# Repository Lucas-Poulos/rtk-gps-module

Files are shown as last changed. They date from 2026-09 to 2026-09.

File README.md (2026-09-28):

# rtk-gps-module

A cheap, solder-down **RTK GNSS module** that gets you centimetre-level
position. Dual-band L1 + L5, castellated edges, and a USB-C port so it also
works on its own with nothing but a cable.

**Status: schematic complete and verified. PCB layout is the next phase.**

```
    ┌──── u.FL ────┐
    │ active       │   50 Ω CPWG, 0.38 mm
    │ dual-band    ├──► ESD ─► bias tee ─► DC block ─► π ─► SAW ─┐
    │ antenna      │    0.25pF   68 nH      100 pF    0R   L1+L5 │
    └──────────────┘        ▲                                    ▼
                            │                            ┌───────────────┐
                    ANT_ON ─┴─ PMOS switch               │   LC29H (DA)  │
                                                         │  dual-band    │
    USB-C ─► ESD ─► BAT54C OR ─► AP2112K 3V3 ────────────┤  RTK rover    │
      │                ▲                                 │               │
      │             5V_IN (carrier)                      │  UART1  1PPS  │
      └─► CH340N ──────────────────────────── UART ──────┤               │
                                        1k/10k divider   └───────┬───────┘
                                                                 │
                              24 castellated pads, 1.27 mm ──────┘
```

## What it does

Feed it **RTCM3 corrections** over the UART — from an NTRIP client on a
phone, a Raspberry Pi or a PC — and it resolves carrier phase to **1–2 cm
horizontal**, versus the 2–3 m you get from ordinary GPS.

Corrections come from the host, so there is **no radio on the board**:
nothing to license, nothing to certify, and one less thing to pay for.

| | |
|---|---|
| Receiver | Quectel LC29H (DA), dual-band RTK rover |
| Bands | L1 / E1 / B1 / G1 **and** L5 / E5a / B2a |
| Constellations | GPS, GLONASS, Galileo, BeiDou, QZSS, SBAS |
| RTK accuracy | ~1–2 cm CEP, open sky, within 1 km of the base |
| Update rate | up to 10 Hz |
| Corrections in | RTCM3 over UART1 |
| Timing out | 1PPS, rising-edge synchronised |
| Supply | 5 V from USB-C **or** 5 V from the carrier board |
| Logic | 3.3 V (plus a 1.8 V debug domain, see below) |
| Interface | USB-C (CH340N) and 24 castellated pads on 1.27 mm |
| **Parts cost** | **$27.10** per board at qty 1 |

The receiver is **88 % of the bill**. Everything else together is $1.56.
Nothing but the receiver is worth cost-optimising.

## Everything else is discrete

There is no way to make an RTK receiver from discrete components — carrier
phase needs a correlator ASIC. So the receiver and its SAW filter are ICs
and *everything around them* is built from single transistors and passives
rather than bought as a block:

- **Antenna bias tee** — a 68 nH choke, a 100 pF block, and a PMOS/NPN pair
  switched by `ANT_ON`, with a 10 Ω resistor limiting a shorted antenna to
  ~330 mA.
- **5 V ORing** — one BAT54C, anodes to USB and to the carrier's 5 V,
  cathode to the LDO. USB and carrier power can both be present and neither
  back-feeds the other.
- **Backup domain** — a second BAT54C ORs 3V3 with an optional external
  cell on `VBCKP_EXT`, so the ephemeris cache survives and the module
  hot-starts in ~1 s instead of cold-starting in ~30 s.
- **RX level shift** — a 1 k / 10 k divider, because `RXD1` is specified
  VIHmax **3.08 V** and a 3.3 V host would exceed it.
- **1PPS indicator** — one MMBT3904, because 1PPS is guaranteed only 2.1 V
  high and would drive an LED dimly while loading the edge.

## The impedance work

Fully derived rather than asserted — see **[docs/impedance.md](docs/impedance.md)**.
Short version:

- The antenna line is a **conductor-backed CPWG**, not microstrip. Solving
  the conformal-mapping model for JLCPCB's 4-layer JLC04161H-3313 stackup
  gives **0.38 mm at 0.2 mm gap → 50.19 Ω**. Treating it as microstrip
  would say 0.41 mm and land it near 47 Ω.
- The SAW's ports are **50 Ω ∥ 5.1 nH**, not 50 Ω, so `L302`/`L303` are
  part of the impedance, not optional.
- The ESD diode is **0.25 pF**. An ordinary ESD part at 10–50 pF would
  shunt the antenna signal away.
- The number lives in `tools/calc_impedance.py`, and `make check` fails
  if the project's RF netclass drifts away from it.

## Pinout

24 castellated pads on 1.27 mm — drops onto 0.1 in perfboard.

**Left edge (J501)**

| Pad | Name | Notes |
|---:|---|---|
| 1 | GND | |
| 2 | 5V_IN | ORed with USB VBUS |
| 3 | 3V3 | LDO output |
| 4 | VBCKP_EXT | optional backup cell / supercap |
| 5 | GND | |
| 6 | TXD1 | receiver → host, NMEA / PQTM |
| 7 | RXD1 | host → receiver, RTCM3 in |
| 8 | 1PPS | rising edge |
| 9 | RESET_N | active low, pulled up on-board |
| 10 | WAKEUP | needs ≥ 3.0 V to wake |
| 11 | VDD_EXT | 2.8 V out, **100 mA max** |
| 12 | GND | |

**Right edge (J502)**

| Pad | Name | Notes |
|---:|---|---|
| 1 | GND | |
| 2 | ANT_ON | antenna switch control |
| 3 | I2C_SDA | via DNP link |
| 4 | I2C_SCL | via DNP link |
| 5 | TXD2 | **1.8 V domain**, via DNP link |
| 6 | RXD2 | **1.8 V domain**, via DNP link |
| 7 | D_SEL1 | **1.8 V domain**, via DNP link |
| 8 | D_SEL2 | **1.8 V domain**, via DNP link |
| 9 | GND | |
| 10–11 | — | spare |
| 12 | GND | |

> **Pads 5–8 on the right edge are not 3.3 V tolerant.** VIHmax is 2.1 V.
> Each reaches the edge only through an unfitted link, so a default board
> cannot present them to a 3.3 V host by accident.

`D_SEL1 = D_SEL2 = 0` selects UART1 and is the on-chip default via 75 kΩ
pulldowns, so the fitted board needs no strapping parts at all.

## Repository layout

```
design/        THE PROJECT. Open it in KiCad, edit it, save it.
  lib/         the two symbols and three footprints stock KiCad lacks
tools/         helpers that READ design/ -- none of them write to it
  check.py             ERC + netlist + sourcing + impedance
  gen_bom.py           BOM, read from the schematic
  calc_impedance.py    the 50 Ω derivation
  fetch_datasheets.py  pulls the vendor PDFs (not committed)
  bootstrap/           the generators that built v1 -- NOT authoritative
Makefile       run `make` to list every target
.githooks/     optional pre-commit hook, ERC errors only
manufacturing/ BOM.md, BOM-dnp.md, bom_jlcpcb.csv
docs/          editing.md, impedance.md, schematic.pdf
datasheets/    README + fetch script; the PDFs are not ours to redistribute
analysis/      ERC report and netlist (gitignored, regenerated on demand)
```

**`design/` is a normal KiCad project.** Edit it directly. Nothing
regenerates it, and nothing in `tools/` writes to it.

## Working on it

```bash
make open       # open in KiCad -- edit and save freely
make check      # ERC + netlist + sourcing + impedance, all read-only
make bom        # rebuild manufacturing/ after a parts change
make            # list every target
```

Read **[docs/editing.md](docs/editing.md)** before changing the RF path
or anything on the LC29H — there are four traps on this board that KiCad
will not warn you about (a 3.08 V limit on `RXD1`, a 1.8 V pin domain,
two supply pins that are outputs, and three pins that must float).

`make check` reads `design/` and never writes to it. It exports a fresh
netlist and a fresh ERC report and asserts against those:

- **ERC** — must be clean *and* the report must be newly written. A stale
  report from an earlier run reads exactly like a pass, and `kicad-cli`
  writes no report at all when the schematic fails to parse. Verified by
  injecting a deliberate fault and confirming ERC caught it on the right
  sub-sheet.
- **Netclass** — the exported per-net class is read back, because KiCad
  accepts a netclass pattern that matches nothing without complaining and
  a 50 Ω line silently falls back to the default track width. *(This
  caught a real bug: `/regex/` patterns are accepted by the file format
  and match nothing — KiCad uses wildcards, and local nets carry their
  sheet path.)*
- **Critical nets** — the RF chain, the bias tee and the RXD1 divider are
  asserted pin by pin, so none of them gets rerouted by accident. Rewire
  one on purpose and it tells you exactly what changed.
- **LC29H pin rules** — grounds grounded, the three RESERVED pins still
  floating, `VDD_EXT` never tied to 3V3.
- **Sourcing** — every fitted part must carry a resolved `Cxxxxx`.
- **Impedance** — the RF netclass width must still match what
  `tools/calc_impedance.py` derives, and still land within 5 % of 50 Ω.

## Building one

The BOM is in [manufacturing/BOM.md](manufacturing/BOM.md), with
`bom_jlcpcb.csv` ready for JLCPCB assembly and
[BOM-dnp.md](manufacturing/BOM-dnp.md) listing the unfitted options.

Prices and stock were read from LCSC on 2026-09-28 and frozen for
traceability — **re-check before ordering.** LC29H stock in particular was
thin (22 pcs). `LC29HBS` (`C21385845`) is the RTK *base station* variant and
`LC29HAA` (`C22403415`) has no RTK engine; both share the footprint, so
check you are buying the one you mean.

You also need an **active dual-band L1+L5 antenna** with NF < 1.5 dB, gain
< 17 dB, and its SAW ahead of its LNA.

## Caveats

- **Not built yet.** The schematic is verified; no board has been
  fabricated, so nothing here is confirmed against hardware.
- **The LC29H (DA) pinout is contested by its own datasheet.** Figure 4
  and Table 6 disagree about pins 15–19. The V1.3 revision history settles
  it in Table 6's favour (the changes applied only to the EA variant), and
  the design follows Table 6 — but those four pins reach the edge only
  through unfitted links, so the board is correct either way.
- Prices are a snapshot, not a quote.

## Licence

Hardware under [CERN-OHL-P v2](LICENSE); the scripts under the same terms.
Permissive — do what you like, no reciprocity required.

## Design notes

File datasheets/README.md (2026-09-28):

# Datasheets

The PDFs this design was transcribed from are **not committed** — they are
Quectel's and Qualcomm's documents, not mine to redistribute. Fetch them:

```bash
python3 tools/fetch_datasheets.py
```

| File | Document | Used for |
|---|---|---|
| `LC29H_Hardware_Design_V1.3.pdf` | Quectel LC29H Series Hardware Design, V1.3 (2024-07-30) | Table 6 pin description, Figure 4 pin assignment, Figure 17 active-antenna reference, Figure 19 land pattern, section 3.2 decoupling |
| `SAW_B39162B8389P810.pdf` | Qualcomm RF360 B8389 SAW RF Filter, V2.1 (2022-11-15) | section 4 pin configuration, section 5 matching circuit (50 Ω ∥ 5.1 nH), section 6 pass bands, Figure 2 land pattern |

Everything transcribed from them is cited in place — see
`tools/bootstrap/gen_custom_symbols.py` and `tools/bootstrap/gen_footprints.py`.

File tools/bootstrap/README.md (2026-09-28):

# Bootstrap generators — not authoritative

**Do not run these.** They produced the first version of `design/`, and
that is all they are for now. `design/` is the source of truth: it is
hand-edited in KiCad, and re-running `gen_project.py` would overwrite
your work with the design as it stood on 2026-09-28.

They are kept because two of them contain work that is hard to redo and
worth reading:

| File | What is worth keeping |
|---|---|
| `gen_custom_symbols.py` | The LC29H pinout, transcribed pin by pin from the hardware design guide's Table 6, with the electrical type of each pin justified in comments. Its `verify()` holds a **second, independent transcription** of the same table — they were written to disagree loudly if either was typed wrong. Also the reasoning that settles the (DA) variant's contradictory pinout. |
| `gen_footprints.py` | The LC29H land pattern derived from Figure 19, including why the 24 pads are in two uneven groups, and the B8389 land pattern from its Figure 2. |
| `gen_project.py` | The parts catalogue: every LCSC number resolved against the live catalogue on 2026-09-28, with the JLCPCB basic/extended split. |
| `wire_sheets.py` | The connectivity, plus a docstring listing the pin traps — duplicated `I/O1` pins on the USBLC6, BAT54C's common cathode on pin 3, KiCad's cathode-is-pin-1 convention. |
| `verify_project.py` | The old 146-check gate. Superseded by `tools/check.py`, which checks the same design without regenerating it. |

If you need any of that, read it. The live equivalents are:

- `tools/check.py` — the checks, read-only
- `tools/gen_bom.py` — the BOM, read from the schematic
- `tools/calc_impedance.py` — the 50 Ω derivation, still used and still
  checked against the project's RF netclass

## If you ever do want to run one

You would be replacing `design/` wholesale. Take a branch first:

```bash
git switch -c regenerate
python3 tools/bootstrap/gen_project.py
git diff --stat design/       # this will be enormous
```

Expect a large diff even with no design change, because KiCad has since
rewritten every file in its own canonical format.

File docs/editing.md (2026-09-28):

# Editing this project

It is a normal KiCad 10 project. Open it, change it, save it.

```bash
make open        # or just double-click design/rtk-gps-module.kicad_pro
```

There is no generator to fight, no regeneration step, and nothing that
overwrites your edits. `design/` is the source of truth.

After you save:

```bash
make check       # ERC + netlist + sourcing + impedance, all read-only
make bom         # rebuild manufacturing/ if you changed parts
make pdf         # re-plot docs/schematic.pdf
```

`make check` never writes to `design/`.

---

## Adding or changing a part

Do it in KiCad. The one thing to remember: **set the `LCSC` field**, or
the part silently vanishes from the BOM at order time. `make check`
catches it:

```
R103 (2.2k) has no resolved LCSC number. Set its LCSC field in KiCad,
or mark it DNP.
```

Resolve the real number first — never invent one:

```bash
python3 ~/.claude/skills/lcsc/scripts/search_lcsc.py "0402 2.2k" --details
```

Then in KiCad: select the symbol, `E`, and set the fields the BOM reads:

| Field | Example | Used for |
|---|---|---|
| `LCSC` | `C25879` | ordering, JLCPCB CSV |
| `MPN` | `0402WGF2201TCE` | the BOM line |
| `Manufacturer` | `UNI-ROYAL` | the BOM line |
| `DNP` | `yes` | excludes it from the fitted BOM |

For a not-fitted part, also add its reason to `DNP_REASON` in
`tools/gen_bom.py` so `BOM-dnp.md` explains why the footprint exists.

Prices live in `PRICES` in `tools/gen_bom.py` — a frozen snapshot from
2026-09-28, kept for traceability rather than accuracy. Refresh before
ordering.

---

## Four things that will bite you

These are all real, all specific to this board, and none of them are
things KiCad warns about.

### 1. `RXD1` cannot take 3.3 V

The LC29H specifies `RXD1` VIHmax **3.08 V**. `R205`/`R212` (1 k/10 k)
divide a 3.3 V host down to 3.0 V, and the divider sits **at the module
pin** so it protects the castellated pad and the USB bridge with one
pair of resistors. Delete it and you are over spec on a $24 part.

### 2. `D_SEL1`/`D_SEL2`, `TXD2`/`RXD2` are a 1.8 V domain

VIHmax is **2.1 V**. They cannot be strapped to `VDD_EXT` (2.8 V) or
3V3. The default `0,0` selects UART1 via internal 75 kΩ pulldowns, which
is what this board wants, so the fitted build needs no strapping parts.

### 3. `VDD_EXT` (pin 7) and `VDD_RF` (pin 9) are OUTPUTS

Typed `power_out` so ERC rejects driving them. `VDD_EXT` is 2.8 V at
100 mA max — tying it to 3V3 shorts two regulators together.

### 4. Pins 2, 4, 17 must float

Datasheet Table 6: *"must be left N/C and cannot be connected to power
or GND."* Typed `no_connect`; `make check` asserts each still lands on
its own unconnected net.

---

## The RF path

If you touch anything between `J301` and `U201` pin 11, read
[impedance.md](impedance.md) first. Three specifics:

- The antenna line is **50 Ω CPWG at 0.38 mm** with a 0.2 mm gap, derived
  in `tools/calc_impedance.py`. If you change the width in the RF
  netclass, `make check` fails until the model agrees.
- The SAW's ports are **50 Ω ∥ 5.1 nH**. `L302`/`L303` are part of the
  impedance, not optional decoration.
- `D301` is chosen for **0.25 pF**, not its clamp voltage. A normal ESD
  diode at 10–50 pF shunts the antenna signal away.

`make check` pins down the exact wiring of the RF chain, the bias tee and
the RXD1 divider. If you rewire one deliberately, it tells you what
changed and where to update the expectation:

```
net '/RF/ANT_RF' was rewired:
       missing ['L301.2']
       extra   ['L301.1']
       If that was deliberate, update CRITICAL_NETS in tools/check.py
```

---

## Netclasses are wildcards, not regex

If `make check` says a net fell back to `Default`, this is why. KiCad's
netclass patterns use `*` and `?` — a pattern written `/^ANT_RF$/` is
accepted by the file format, displays correctly in the GUI, and **matches
nothing**. Local nets also carry their sheet path (`/RF/ANT_RF`), so a
pattern for one needs a leading `*`.

This already bit the project once: the 50 Ω antenna line was silently on
the default track width. That is the only reason `make check` reads the
exported per-net class back.

---

## The pre-commit hook

`make hooks` installs one. It blocks on **ERC errors only** — never on
warnings, never on formatting, and it skips entirely while KiCad has the
project open. `make unhook` removes it; `git commit --no-verify` bypasses
it once.

---

## What nothing checks

- **The pinout tables in `README.md`** — hand-maintained. If you change
  `J501`/`J502`, change them too.
- **Whether the design works.** No board has been fabricated. ERC proves
  the netlist is self-consistent; it says nothing about whether the
  circuit is correct.

---

## Where the old generators went

`tools/bootstrap/`. They built the first version of `design/` and are no
longer authoritative — see the README there. Worth reading for the
datasheet transcription and the reasoning about the LC29H's
self-contradictory pinout, but do not run them: they would overwrite
your edits with the design as it stood on 2026-09-28.

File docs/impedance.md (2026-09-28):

# Impedance and the RF path

Everything on this board that matters at 1.2–1.6 GHz, and why each number
is what it is. The numbers here are not prose — `tools/calc_impedance.py`
derives them, and `make check` fails if the project's RF netclass drifts
away from what the model says.

```
make impedance
```

## Why the receiver cares

The LC29H hardware design guide types pin 11 (`RF_IN`) as an analog input
with **"50 Ω characteristic impedance"** (Table 6) and asks for the track to
it to be controlled and short. A GNSS signal arrives at roughly −130 dBm.
There is no margin to give away: every dB lost between the antenna and the
correlator is a dB of carrier-to-noise, and RTK needs carrier *phase*, which
degrades faster than pseudorange does as C/N₀ falls.

## The line

The antenna track is a **conductor-backed coplanar waveguide** (CPWG): a
signal trace on L1 with coplanar ground pour either side *and* a solid
ground plane on L2 underneath. That is not the same thing as microstrip,
and the difference is not small — the coplanar gaps add capacitance, so a
CPWG needs a **narrower** trace than a microstrip for the same impedance.

| Model | Width for 50 Ω |
|---|---|
| Plain microstrip (wrong here) | 0.410 mm |
| CPWG, 0.2 mm gap (correct) | 0.382 mm |
| **Built** | **0.38 mm** → 50.19 Ω |

Building the microstrip number on a board that is actually CPWG would land
the line near 47 Ω. That is inside most fab tolerances and would probably
still work — which is exactly why it is worth getting right on purpose
rather than by luck.

### Stackup

JLCPCB four-layer 1.6 mm, **JLC04161H-3313** — their default, and the one
this board is costed against.

```
L1   35 µm copper        <- antenna track here
     0.2104 mm prepreg   <- h
L2   ground plane        <- solid, unbroken under the whole RF path
     1.065 mm core
L3
     0.2104 mm prepreg
L4   35 µm copper
```

`εr = 4.3` for Shengyi S1000-2M around 1.5 GHz. The datasheet quotes 4.4 at
1 MHz and it falls with frequency.

### The model

Conformal mapping, per Simons, *Coplanar Waveguide Circuits, Components and
Systems*, ch. 3:

```
a  = W/2
b  = W/2 + G
k1 = a/b
k2 = tanh(πa/2h) / tanh(πb/2h)
R  = K(k)/K(k')          K = complete elliptic integral, 1st kind

εeff = (1 + εr·R2/R1) / (1 + R2/R1)
Z0   = 60π / √εeff / (R1 + R2)
```

### Tolerance

| Variation | Z₀ |
|---|---|
| εr = 4.1 | 51.25 Ω |
| εr = 4.3 (nominal) | 50.19 Ω |
| εr = 4.5 | 49.19 Ω |
| W − 0.02 mm (etch) | 51.76 Ω |
| W + 0.02 mm (etch) | 48.72 Ω |

Worst case lands inside ±4 %. JLCPCB hold ±10 % on controlled impedance, so
the design is not the limiting factor.

### Length

εeff = 3.107, so the guided wavelength at L1 (1575.42 MHz) is **108 mm**.
Keep the antenna track under λ/20 = **5.4 mm** and its length stops
mattering — no tuning, no stub effects, nothing to model. The u.FL connector
should sit directly beside the SAW, and the SAW directly beside pin 11.

## Layout rules for the PCB stage

Not yet built — the PCB is the next phase — but these follow from the above
and should be treated as constraints, not preferences.

1. **L2 is solid ground under the entire RF path.** A split or a via
   antipad chain under the track changes the return path, and the impedance
   with it. This is the single easiest way to ruin the work above.
2. **Stitch the coplanar pours** either side of the track with vias to L2 at
   ≤ λ/20 ≈ 5 mm — closer near the connector and the SAW. Unstitched
   coplanar pour is a resonator, not a ground.
3. **Keep the chain short and straight**: u.FL → ESD → bias tee tap →
   DC block → π → SAW → RF_IN. Quectel's guide asks for the SAW close to
   pin 11 specifically.
4. **L301 (the bias choke) taps the line, it does not sit in it.** Route the
   proximal pad of L301 onto the RF trace; the DC side goes away from it.
5. **No other signal crosses the RF path on any layer.** The switching
   antenna supply, the USB pair and the UART all stay clear.
6. **The u.FL ground pads want their own via cluster**, not a thin neck to
   the pour.

## The rest of the RF chain

### Bias tee

`L301` = 68 nH wirewound (Murata LQW15AN68NG00D). Quectel specify ≥ 68 nH.
The point of the choke is to be a high impedance across both bands while
passing DC:

| Band | f | \|Z\| of 68 nH |
|---|---|---|
| L5 / E5a / B2a | 1176.45 MHz | 502 Ω |
| L1 / E1 / B1 | 1575.42 MHz | 673 Ω |

Both are ≫ 50 Ω, so the tap costs a small fraction of a dB. A **ferrite
bead must not be substituted here** — a bead is deliberately lossy at these
frequencies, which is the opposite of what a bias tee needs.

`C301` = 100 pF C0G blocks that DC out of the receiver. At 1.5 GHz its
reactance is ~1 Ω, invisible in a 50 Ω line.

### ESD

`D301` = RF1256-000, **0.25 pF** junction capacitance. The LC29H guide caps
this at 0.6 pF. An ordinary ESD diode at 10–50 pF would sit across the
antenna node as a shunt of a few ohms at L1 and simply short the signal
away. This is a case where the "equivalent part" is not equivalent at all.

### The SAW, and its matching

`FL301` = Qualcomm RF360 **B39162B8389P810**, the dual-band part Quectel
names in their own reference design.

| | Band 1 | Band 2 |
|---|---|---|
| Centre | 1176.45 MHz | 1583 MHz |
| Pass | 1166.22–1186.68 | 1559–1607 |
| Insertion loss (typ) | 1.0 dB | 1.8 dB |
| Covers | L5, E5a, B2a | L1, E1, B1, G1 |

Out-of-band rejection is 20–39 dB, which is the point: it keeps LTE band 3
and the ISM bands out of the front end.

**An L1-only SAW here would be a design bug, not a cost saving.** Most
1575.42 MHz GNSS SAWs on LCSC are single-band; dropping one in deletes L5
entirely, and with it the dual-frequency ionosphere cancellation that makes
this an RTK receiver rather than a plain GPS.

The datasheet gives the port impedance as **50 Ω ∥ 5.1 nH**, not 50 Ω.
`L302` and `L303` are those two shunt inductors. Omitting them leaves the
filter mismatched at both ports — it still passes signal, so the mistake
survives bring-up and shows up only as unexplained lost sensitivity.

### π network

`R301` fitted at 0 Ω, `C302` and `C303` unfitted. Somewhere to retune if a
particular antenna turns out to want it, at the cost of two empty pads.

## Antenna requirements

From the LC29H guide, for RTK specifically:

- Active antenna, **noise figure < 1.5 dB**, **total gain < 17 dB**
- The antenna's own **SAW must be in front of its LNA**, not behind it.
  Quectel are explicit: *"DO NOT place the LNA in the front."* An
  LNA-first antenna amplifies every out-of-band transmitter nearby into
  compression before anything has filtered it.
- Dual-band L1+L5. A single-band antenna makes the whole L5 path pointless.

The board supplies the antenna from `VDD_RF` (= VCC, 3.3 V) through the
switch on sheet 3, current-limited to ~330 mA by `R302`.

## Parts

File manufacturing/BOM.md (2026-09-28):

# Bill of Materials

`rtk-gps-module` rev A. Generated by `tools/gen_bom.py` from the
schematic netlist -- do not edit by hand.

- **53 fitted parts** in **29 lines**
- **9 not fitted** (see `BOM-dnp.md`)
- Prices and stock read from LCSC on **2026-09-28** and frozen here for traceability. Re-check before ordering.

## Cost

| | |
|---|---|
| Parts, one board, qty-1 pricing | **$27.10** |
| of which the LC29H receiver | $23.94 (88 %) |
| of which the dual-band SAW | $1.60 |
| everything else | $1.56 |
| JLCPCB basic parts / extended | 38 / 15 |
| JLCPCB extended-part feeder fees | $39.00 one-off |

The receiver is 90 % of the bill. Nothing else on the board is worth
optimising until that changes.

## Fitted

| Qty | Refs | Value | MPN | LCSC | Pkg | Unit $ | Ext $ | Stock |
|----:|---|---|---|---|---|----:|----:|----:|
| 1 | U201 | LC29HDAMD | LC29HDAMD | [C20748061](https://www.lcsc.com/search?q=C20748061) | Quectel_LC29H_LCC-24_12.2x16.0mm | 23.9364 | 23.936 | 22 |
| 1 | FL301 | B8389 | B39162B8389P810 | [C5556161](https://www.lcsc.com/search?q=C5556161) | SAW_RF360_SMD1411-5P_1.4x1.1mm | 1.6036 | 1.604 | 130 |
| 1 | U401 | CH340N | CH340N | [C2977777](https://www.lcsc.com/search?q=C2977777) | SOIC-8_3.9x4.9mm_P1.27mm | 0.5701 | 0.570 | 14,211 |
| 3 | C101, C103, C201 | 10uF | CL21A106KAYNNNE | [C15850](https://www.lcsc.com/search?q=C15850) | C_0805_2012Metric | 0.0773 | 0.232 | 3,505,306 |
| 1 | U101 | AP2112K-3.3 | AP2112K-3.3TRG1 | [C23380830](https://www.lcsc.com/search?q=C23380830) | SOT-23-5 | 0.1089 | 0.109 | 31,470 |
| 1 | D301 | RF1256-000 | RF1256-000 | [C207186](https://www.lcsc.com/search?q=C207186) | D_0603_1608Metric | 0.0794 | 0.079 | 8,172 |
| 2 | L302, L303 | 5.1nH | LQW15AN5N1B00D | [C408161](https://www.lcsc.com/search?q=C408161) | L_0402_1005Metric | 0.0386 | 0.077 | 16,817 |
| 1 | J101 | USB-C 16P | TYPE-C 16PIN 2MD(073) | [C2765186](https://www.lcsc.com/search?q=C2765186) | USB_C_Receptacle_HRO_TYPE-C-31-M-12 | 0.0742 | 0.074 | 1,171,811 |
| 1 | Q301 | AO3401A | AO3401A | [C15127](https://www.lcsc.com/search?q=C15127) | SOT-23 | 0.0716 | 0.072 | 715,902 |
| 1 | L301 | 68nH | LQW15AN68NG00D | [C108965](https://www.lcsc.com/search?q=C108965) | L_0402_1005Metric | 0.0638 | 0.064 | 59,343 |
| 9 | C102, C104, C106, C202, C204, C205, C305, C401, C402 | 100nF | CL05B104KO5NNNC | [C1525](https://www.lcsc.com/search?q=C1525) | C_0402_1005Metric | 0.0060 | 0.054 | 16,407,331 |
| 1 | D101 | USBLC6-2SC6 | USBLC6-2SC6 | [C2827654](https://www.lcsc.com/search?q=C2827654) | SOT-23-6 | 0.0446 | 0.045 | 90,097 |
| 1 | J301 | u.FL | BWU.FL-IPEX1 | [C5137195](https://www.lcsc.com/search?q=C5137195) | U.FL_Hirose_U.FL-R-SMT-1_Vertical | 0.0398 | 0.040 | 704,735 |
| 1 | D103 | SD05 | SD05 | [C502527](https://www.lcsc.com/search?q=C502527) | D_SOD-323 | 0.0305 | 0.030 | 858,741 |
| 1 | C105 | 4.7uF | CL10A475KO8NNNC | [C19666](https://www.lcsc.com/search?q=C19666) | C_0603_1608Metric | 0.0236 | 0.024 | 1,373,603 |
| 2 | Q302, Q501 | MMBT3904 | MMBT3904 | [C20526](https://www.lcsc.com/search?q=C20526) | SOT-23 | 0.0108 | 0.022 | 2,033,567 |
| 2 | C301, C304 | 100pF | 0402CG101J500NT | [C1546](https://www.lcsc.com/search?q=C1546) | C_0402_1005Metric | 0.0078 | 0.016 | 266,701 |
| 2 | D102, D104 | BAT54C | BAT54C | [C916424](https://www.lcsc.com/search?q=C916424) | SOT-23 | 0.0072 | 0.014 | 1,002,652 |
| 1 | D501 | GREEN 1PPS | KT-0603G | [C12624](https://www.lcsc.com/search?q=C12624) | LED_0603_1608Metric | 0.0122 | 0.012 | 366,908 |
| 2 | C107, C203 | 33pF | 0402CG330J500NT | [C1562](https://www.lcsc.com/search?q=C1562) | C_0402_1005Metric | 0.0049 | 0.010 | 690,617 |
| 1 | D105 | RED | KT-0603R | [C2286](https://www.lcsc.com/search?q=C2286) | LED_0603_1608Metric | 0.0073 | 0.007 | 8,154,450 |
| 6 | R201, R204, R212, R303, R304, R501 | 10k | 0402WGF1002TCE | [C25744](https://www.lcsc.com/search?q=C25744) | R_0402_1005Metric | 0.0005 | 0.003 | 20,674,699 |
| 3 | R103, R205, R502 | 1k | 0402WGF1001TCE | [C11702](https://www.lcsc.com/search?q=C11702) | R_0402_1005Metric | 0.0005 | 0.002 | 12,617,545 |
| 2 | R301, R401 | 0R | 0402WGF0000TCE | [C17168](https://www.lcsc.com/search?q=C17168) | R_0402_1005Metric | 0.0005 | 0.001 | 18,421,967 |
| 2 | R101, R102 | 5.1k | 0402WGF5101TCE | [C25905](https://www.lcsc.com/search?q=C25905) | R_0402_1005Metric | 0.0004 | 0.001 | 8,446,095 |
| 1 | R213 | 22R | 0402WGF220JTCE | [C25092](https://www.lcsc.com/search?q=C25092) | R_0402_1005Metric | 0.0006 | 0.001 | 4,094,909 |
| 1 | R202 | 100k | 0402WGF1003TCE | [C25741](https://www.lcsc.com/search?q=C25741) | R_0402_1005Metric | 0.0005 | 0.001 | 15,436,416 |
| 1 | R203 | 4.7k | 0402WGF4701TCE | [C25900](https://www.lcsc.com/search?q=C25900) | R_0402_1005Metric | 0.0005 | 0.000 | 9,379,077 |
| 1 | R302 | 10R | 0402WGF100JTCE | [C25077](https://www.lcsc.com/search?q=C25077) | R_0402_1005Metric | 0.0005 | 0.000 | 4,398,696 |

## Notes

- **LC29HDAMD** (`C20748061`, U201) -- THE cost and THE stock risk. LC29HBS (C21385845, RTK base) and LC29HAA (C22403415, no RTK engine) share the footprint
- **B39162B8389P810** (`C5556161`, FL301) -- dual-band L1+L5. Do NOT substitute an L1-only SAW -- it deletes the second band RTK depends on
- **LQW15AN5N1B00D** (`C408161`, L302, L303) -- 5.1nH is the SAW's specified port match, not a rounding of 5nH
- **LQW15AN68NG00D** (`C108965`, L301) -- wirewound, >=68nH per the Quectel reference. A ferrite bead here would eat the antenna signal
- **RF1256-000** (`C207186`, D301) -- 0.25pF junction capacitance. The LC29H guide caps this at 0.6pF -- an ordinary ESD diode detunes the antenna

## Not purchased

Board features that carry a footprint but nothing to order.

- `J501` LEFT EDGE -- Castellated_1x12_P1.27mm
- `J502` RIGHT EDGE -- Castellated_1x12_P1.27mm

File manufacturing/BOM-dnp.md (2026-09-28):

# Not-fitted parts

Footprints deliberately left unpopulated. Each is a documented
option, not an omission -- fitting one changes a behaviour the
default build does not want.

| Ref | Value | Pkg | Why it exists |
|---|---|---|---|
| `C302` | DNP | C_0402_1005Metric | pi-match shunt, antenna side -- fit only if the antenna needs it |
| `C303` | DNP | C_0402_1005Metric | pi-match shunt, filter side -- fit only if the antenna needs it |
| `R206` | 0R | R_0402_1005Metric | pull D_SEL1 high to select SPI/I2C instead of UART1 |
| `R207` | 0R | R_0402_1005Metric | pull D_SEL2 high to select I2C instead of UART1 |
| `R208` | 0R | R_0402_1005Metric | brings I2C_SDA out to the castellated edge |
| `R209` | 0R | R_0402_1005Metric | brings I2C_SCL out to the castellated edge |
| `R210` | 0R | R_0402_1005Metric | brings TXD2 (1.8 V debug UART) out to the castellated edge |
| `R211` | 0R | R_0402_1005Metric | brings RXD2 (1.8 V debug UART) out to the castellated edge |
| `R305` | 0R | R_0402_1005Metric | bypasses the ANT_ON switch to power the antenna unconditionally |

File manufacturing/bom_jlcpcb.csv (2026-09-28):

Comment | Designator | Footprint | LCSC Part #
LC29HDAMD | U201 | Quectel_LC29H_LCC-24_12.2x16.0mm | C20748061
B8389 | FL301 | SAW_RF360_SMD1411-5P_1.4x1.1mm | C5556161
CH340N | U401 | SOIC-8_3.9x4.9mm_P1.27mm | C2977777
10uF | C101, C103, C201 | C_0805_2012Metric | C15850
AP2112K-3.3 | U101 | SOT-23-5 | C23380830
RF1256-000 | D301 | D_0603_1608Metric | C207186
5.1nH | L302, L303 | L_0402_1005Metric | C408161
USB-C 16P | J101 | USB_C_Receptacle_HRO_TYPE-C-31-M-12 | C2765186
AO3401A | Q301 | SOT-23 | C15127
68nH | L301 | L_0402_1005Metric | C108965
100nF | C102, C104, C106, C202, C204, C205, C305, C401, C402 | C_0402_1005Metric | C1525
USBLC6-2SC6 | D101 | SOT-23-6 | C2827654
u.FL | J301 | U.FL_Hirose_U.FL-R-SMT-1_Vertical | C5137195
SD05 | D103 | D_SOD-323 | C502527
4.7uF | C105 | C_0603_1608Metric | C19666
MMBT3904 | Q302, Q501 | SOT-23 | C20526
100pF | C301, C304 | C_0402_1005Metric | C1546
BAT54C | D102, D104 | SOT-23 | C916424
GREEN 1PPS | D501 | LED_0603_1608Metric | C12624
33pF | C107, C203 | C_0402_1005Metric | C1562
RED | D105 | LED_0603_1608Metric | C2286
10k | R201, R204, R212, R303, R304, R501 | R_0402_1005Metric | C25744
1k | R103, R205, R502 | R_0402_1005Metric | C11702
0R | R301, R401 | R_0402_1005Metric | C17168
5.1k | R101, R102 | R_0402_1005Metric | C25905
22R | R213 | R_0402_1005Metric | C25092
100k | R202 | R_0402_1005Metric | C25741
4.7k | R203 | R_0402_1005Metric | C25900
10R | R302 | R_0402_1005Metric | C25077

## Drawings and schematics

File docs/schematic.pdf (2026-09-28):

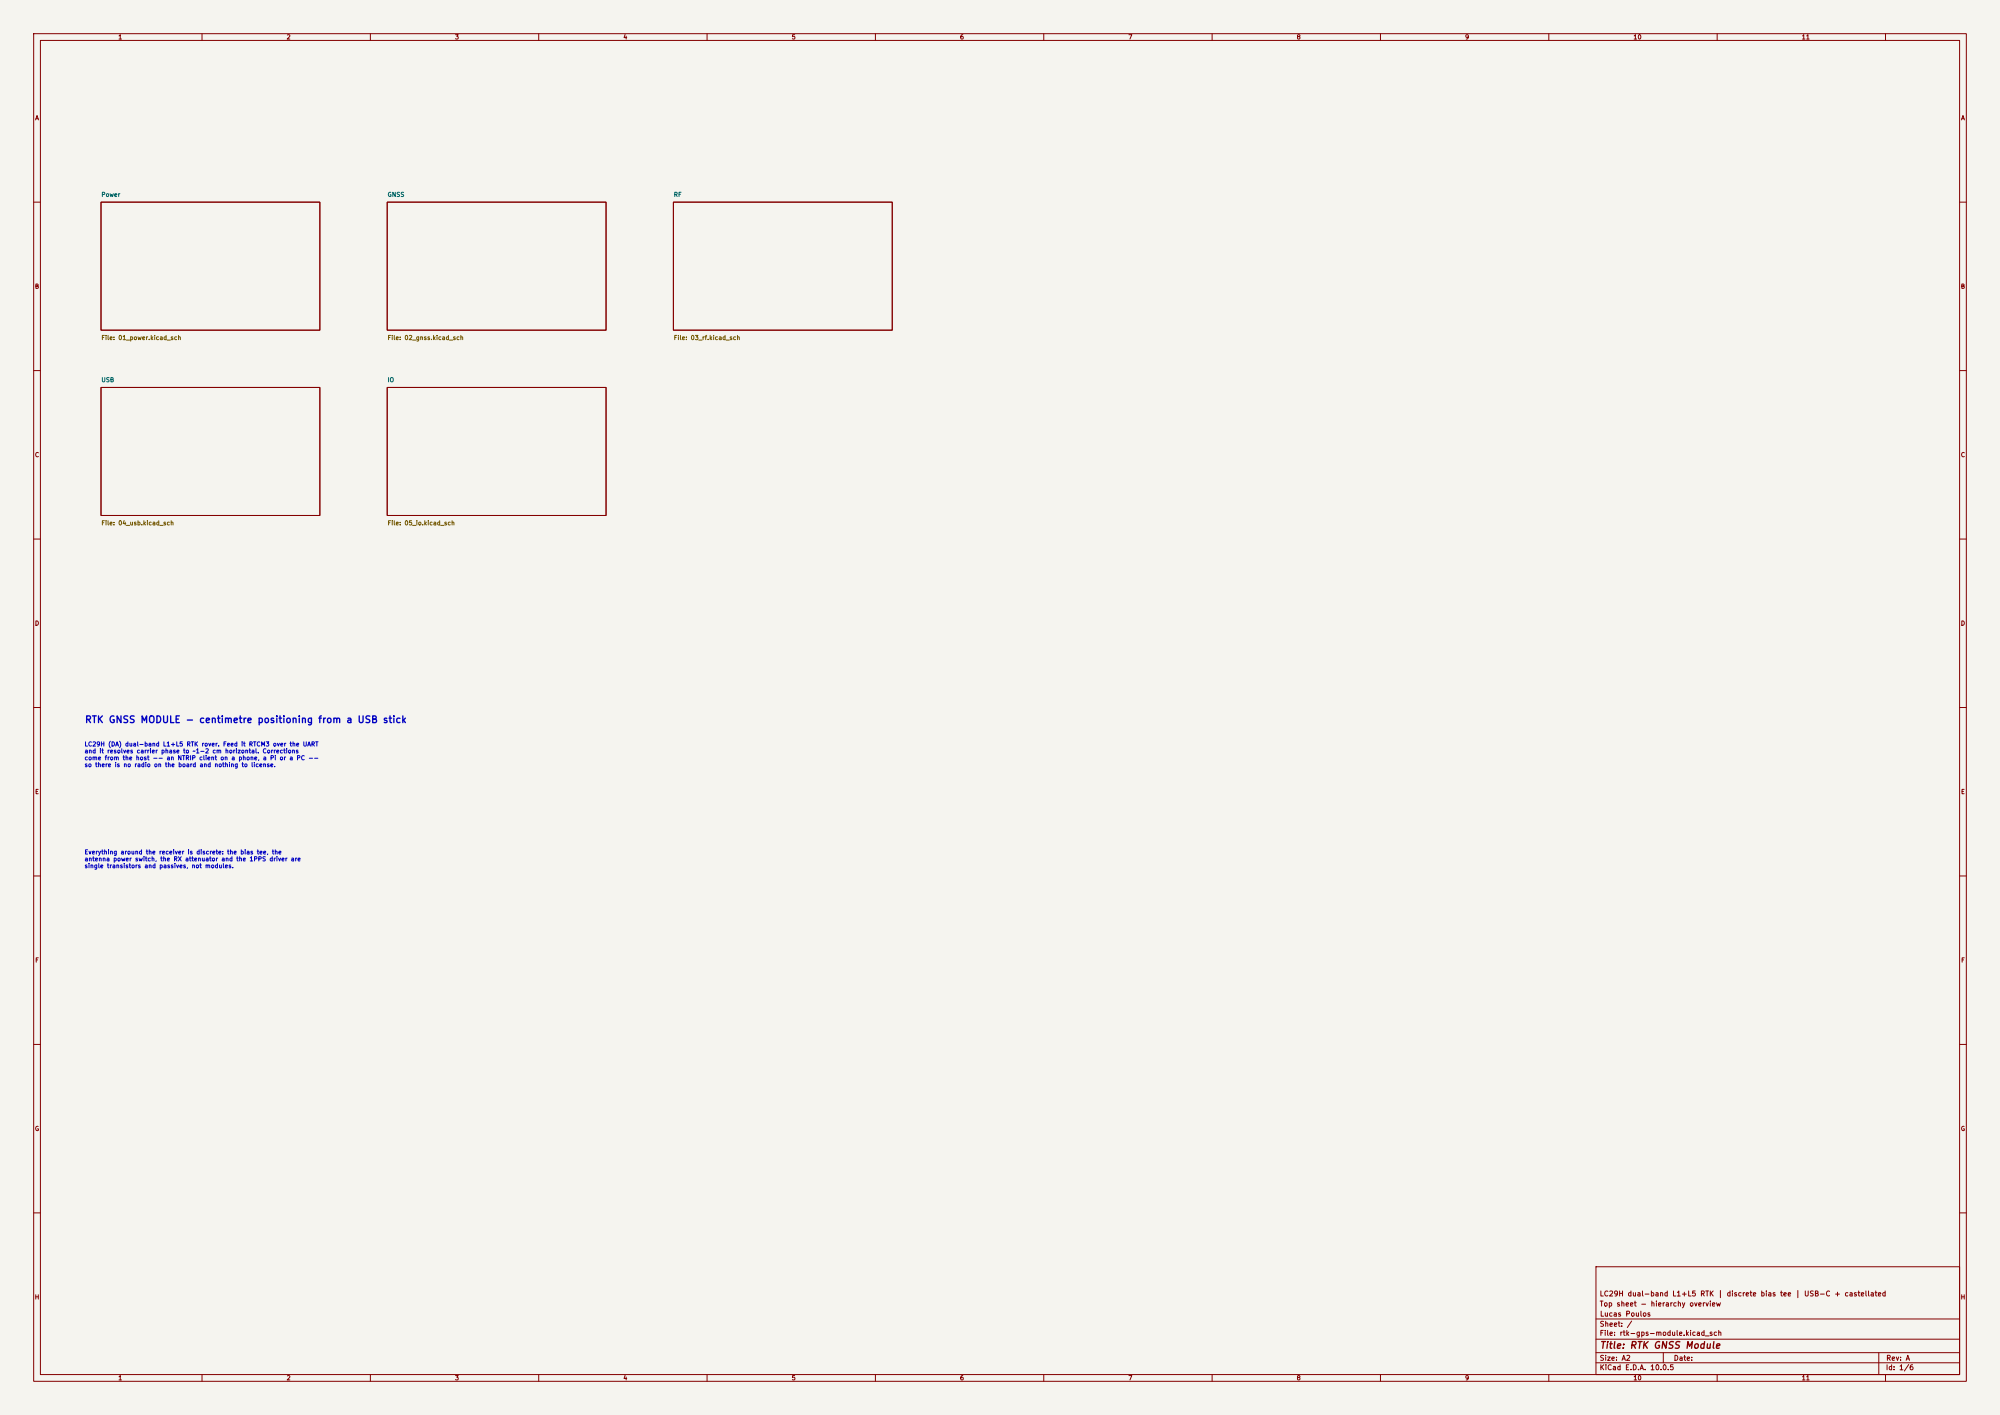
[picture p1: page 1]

File: 03_rf.kicad_sch RTK GNSS MODULE - centimetre positioning from a USB stick

single transistors and passives, not modules. LC29H (DA) dual-band L1+L5 RTK rover. Feed it RTCM3 over the UART and it resolves carrier phase to ~1-2 cm horizontal. Corrections come from the host -- an NTRIP client on a phone, a Pi or a PC --

so there is no radio on the board and nothing to license.

Everything around the receiver is discrete: the bias tee, the antenna power switch, the RX attenuator and the 1PPS driver are

LC29H dual-band L1+L5 RTK | discrete bias tee | USB-C + castellated
Top sheet - hierarchy overview
Lucas Poulos
Sheet: /
File: rtk-gps-module.kicad_sch
Title: RTK GNSS Module

Size: A2 | Rev: A
KiCad E.D.A. 10.0.5 | Id: 1/6

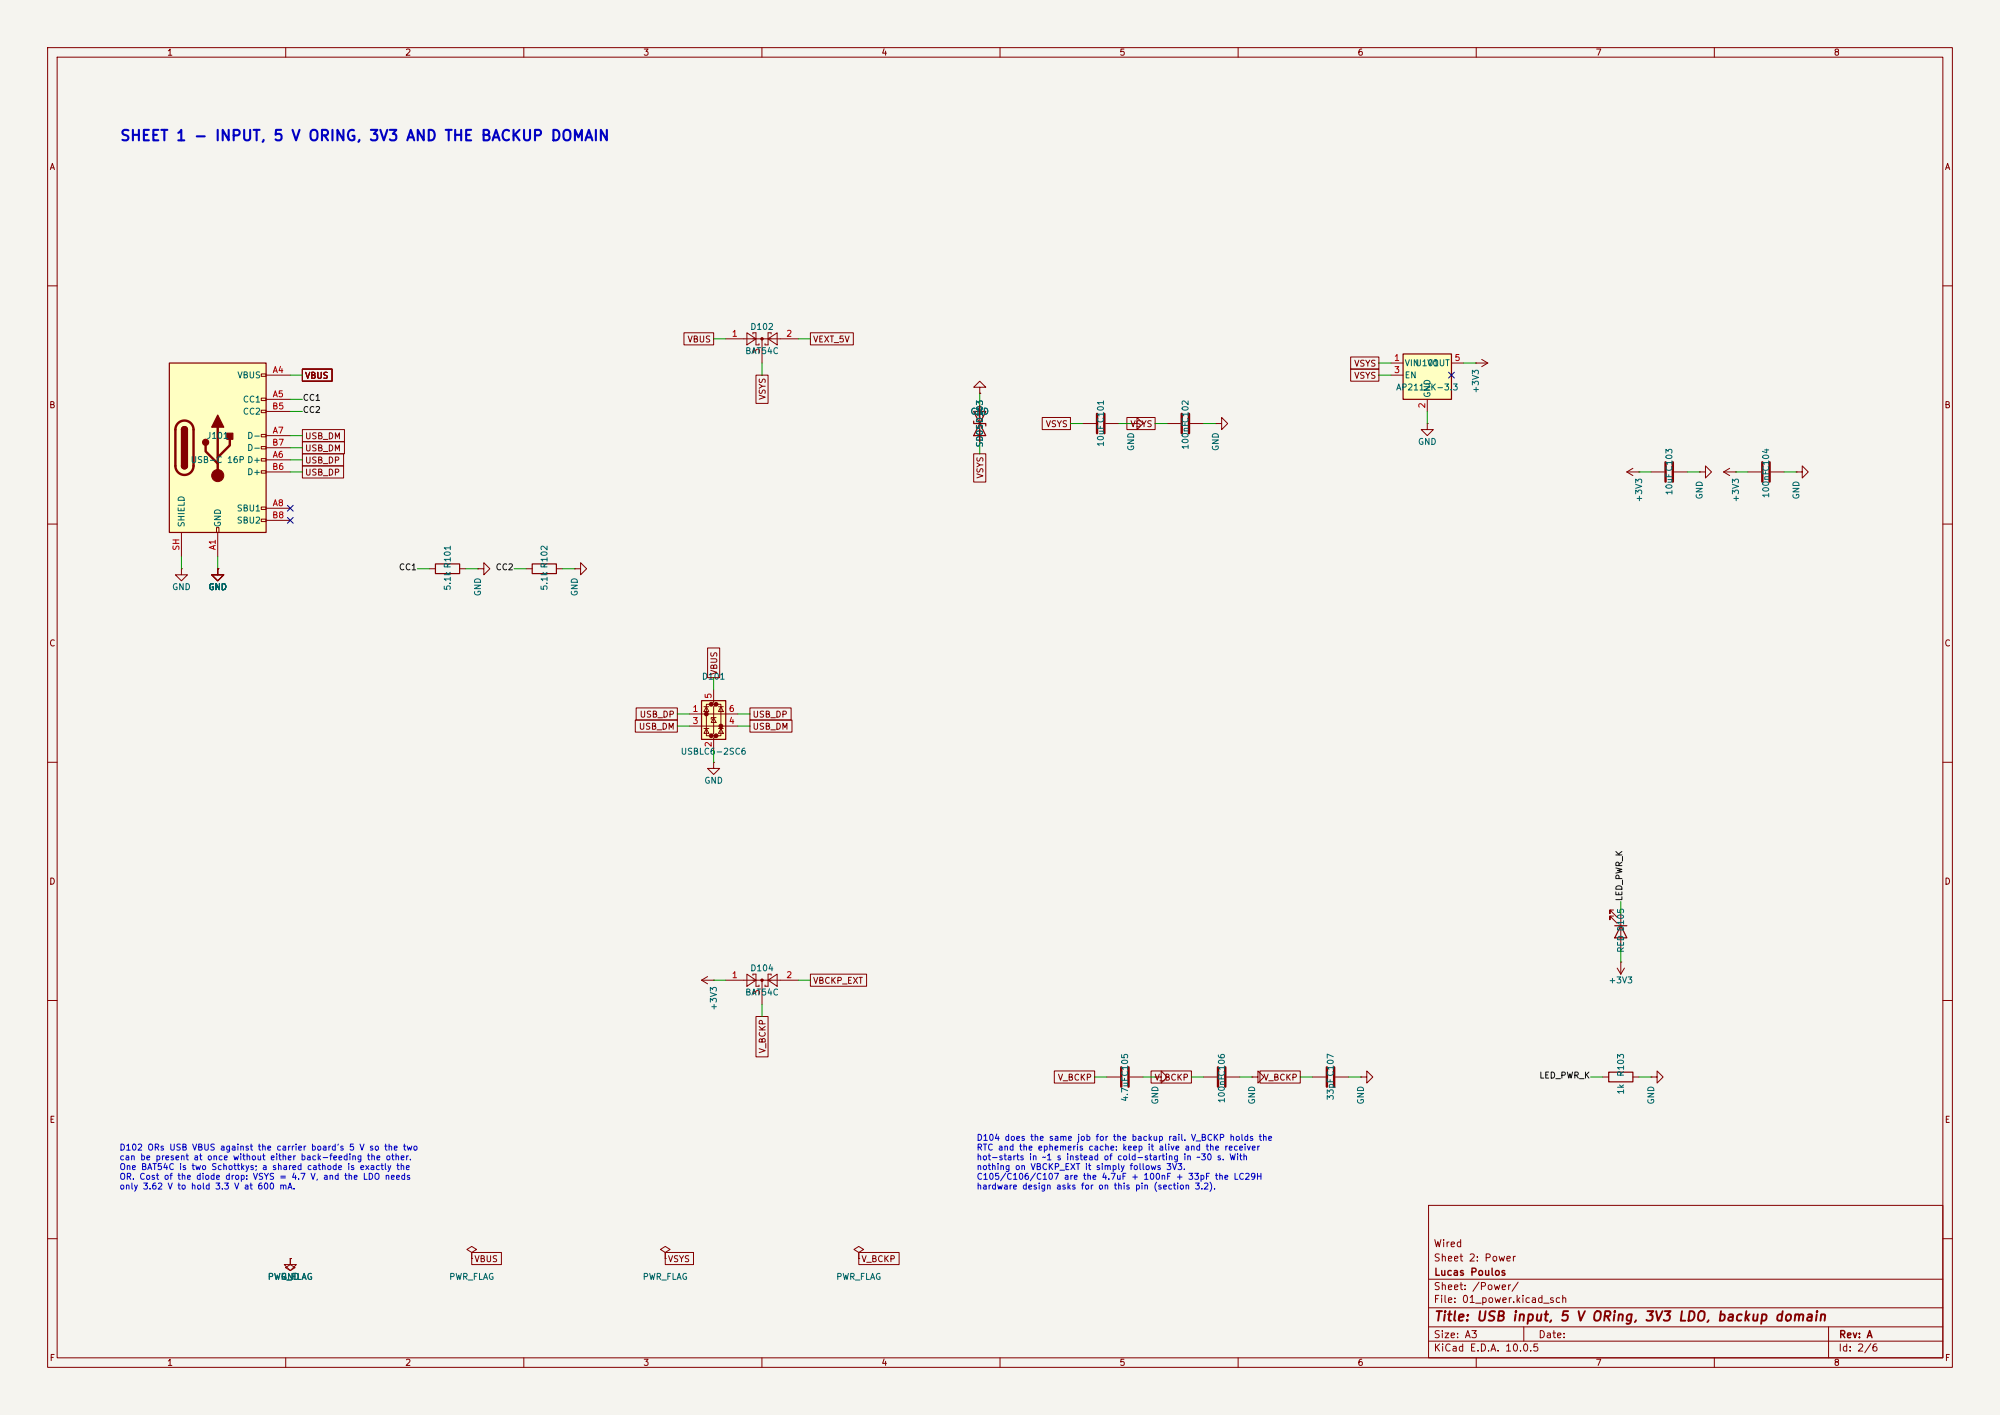
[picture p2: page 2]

SHEET 1 - INPUT, 5 V ORING, 3V3 AND THE BACKUP DOMAIN

D102 ORs USB VBUS against the carrier board's 5 V so the two

nothing on VBCKP_EXT it simply follows 3V3. C105/C106/C107 are the 4.7uF + 100nF + 33pF the LC29H

hardware design asks for on this pin (section 3.2).

Wired
Sheet 2: Power
Lucas Poulos
Sheet: /Power/
File: 01_power.kicad_sch
Title: USB input, 5 V ORing, 3V3 LDO, backup domain

AB

C

D

E

AB

C

D

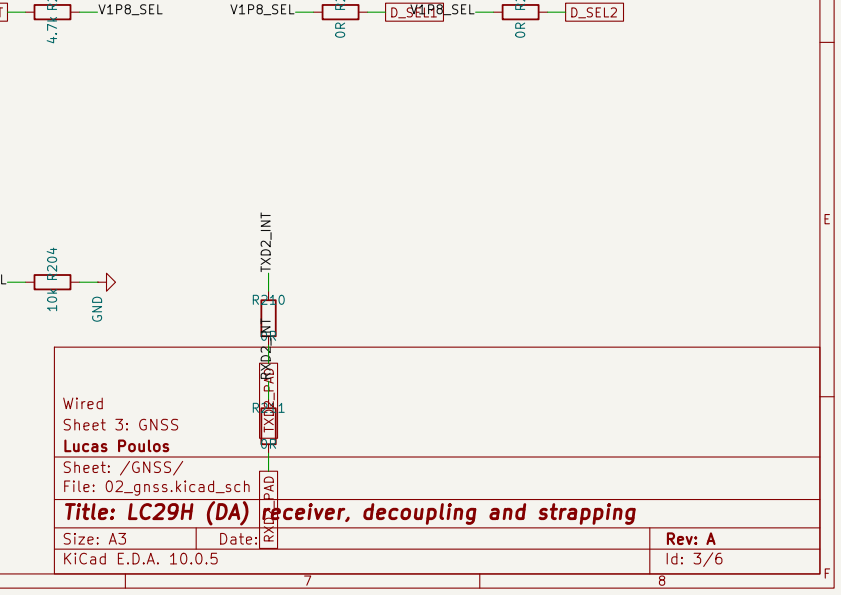
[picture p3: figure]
File: 02_gnss.kicad_sch; Sheet: /GNSS/; Lucas Poulos; Sheet 3: GNSS; D_SEL1 RXD2_PAD

E

# Title: LC29H (DA) receiver, decoupling and strapping

Wired | R212 10k R202 100k GND C205 100nF

0R +3V3

R205

1k GND | GND | R203 C204 | 4.7k 100nF

R213

22R

GND

R209

0R

R208

0R | R207 0R
WAKEUP 1 | RSVD

2

1PPS 3

4 D_SEL1 5 D_SEL2 6

VDD_EXT 7 | RESET_N 8
VDD_RF 9 | GND 10 RF_IN 11 | 123
ANT_ON | 14
TXD2 | 15 RXD2 | 16 RSVD 17
I2C_SDA | 18
I2C_SCL | 19
TXD1 | 20 RXD1 | 21 V_BCKP 22 | VCC 23 | GND 24 U201
LC29HDAMD +3V3 | GND R204 10k +3V3 | GND | R201 10k +3V3
0R C203 33pF | C201 10uF C202 100nF | R206 0R GND | +3V3 | GND | GND
V_BCKP | TXD2_PAD

RESET_N

D_SEL2 PPS
ANT_ON
D_SEL1 RF_IN

D_SEL2

VDD_EXT | UART_TX
VDD_EXT | RX_BUS SDA_PAD
RESET_N | WAKEUP | SCL_PAD

WAKEUP

RESET_N

VDD_RF

VDD_EXT | RXD2_INT | V1P8_SEL TXD2_INT SCL_INT V1P8_SEL | RXD1_NET TXD1_RAW SDA_INT

SDA_INT SCL_INT

TXD1_RAW
RXD1_NET RXD2_INT
TXD2_INT | V1P8_SEL | V1P8_SEL | RXD1_NET D_SEL1/D_SEL2 pick the host interface. Both are pulled down

internally by 75k, and 0,0 selects UART1 -- which is what this board wants, so the default needs no parts. R206/R207 are DNP

links to a 1.9 V node for the other three combinations. The 1.9 V comes from dividing VDD_EXT 2.8 V by 4.7k/10k:

tying D_SEL to VDD_EXT directly would exceed VIHmax = 2.1 V. RX LEVEL. RXD1 is specified VIHmax = 3.08 V (Table 6) and the CH340N drives a full 3.3 V. R205/R212 divide by 10/11 -> 3.0 V,

inside spec and still far above the 1.75 V VIHmin. The divider sits AT the module pin, so it protects the castellated RXD1

pad and the USB bridge with one pair of resistors instead of one pair per source. Source impedance 909 R into ~15 pF is a 14 ns edge -- negligible against a 1.09 us bit at 921600 baud.

# SHEET 2 - LC29H (DA) DUAL-BAND RTK RECEIVER GND +3V3

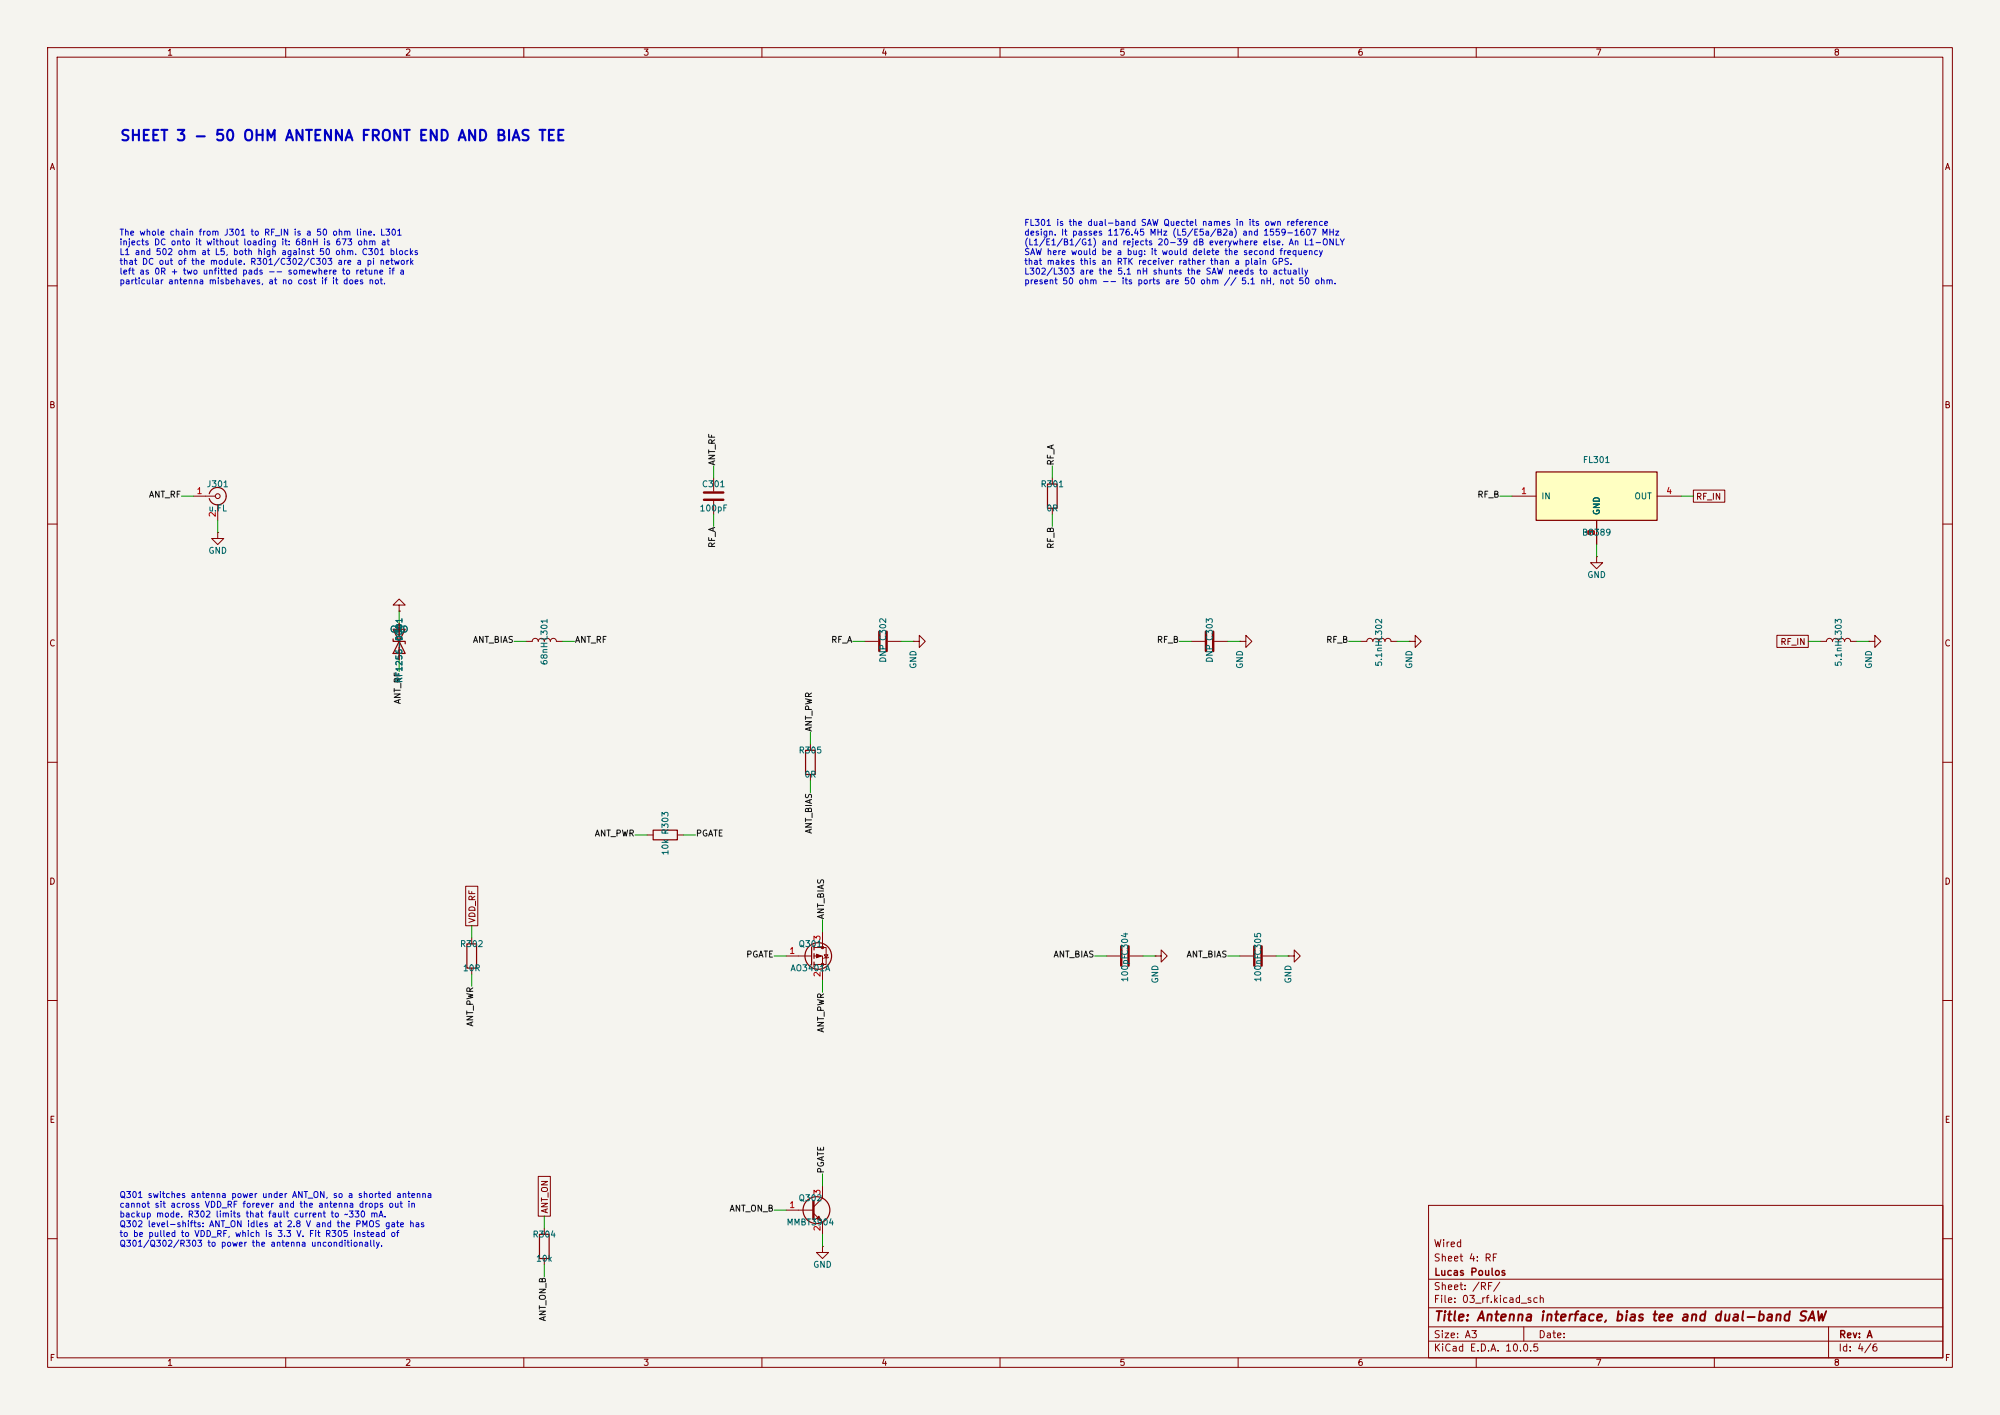
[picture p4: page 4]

SHEET 3 - 50 OHM ANTENNA FRONT END AND BIAS TEE

FL301 is the dual-band SAW Quectel names in its own reference design. It passes 1176.45 MHz (L5/E5a/B2a) and 1559-1607 MHz

The whole chain from J301 to RF_IN is a 50 ohm line. L301
injects DC onto it without loading it: 68nH is 673 ohm at L1 and 502 ohm at L5, both high against 50 ohm. C301 blocks

(L1/E1/B1/G1) and rejects 20-39 dB everywhere else. An L1-ONLY SAW here would be a bug: it would delete the second frequency

that DC out of the module. R301/C302/C303 are a pi network
left as 0R + two unfitted pads -- somewhere to retune if a
particular antenna misbehaves, at no cost if it does not. GNDD301 RF1256-000

that makes this an RTK receiver rather than a plain GPS. L302/L303 are the 5.1 nH shunts the SAW needs to actually

present 50 ohm -- its ports are 50 ohm // 5.1 nH, not 50 ohm.

Q301 switches antenna power under ANT_ON, so a shorted antenna
cannot sit across VDD_RF forever and the antenna drops out in
backup mode. R302 limits that fault current to ~330 mA. Q302 level-shifts: ANT_ON idles at 2.8 V and the PMOS gate has

to be pulled to VDD_RF, which is 3.3 V. Fit R305 instead of Q301/Q302/R303 to power the antenna unconditionally.

Wired
Sheet 4: RF
Lucas Poulos
Sheet: /RF/
File: 03_rf.kicad_sch
Title: Antenna interface, bias tee and dual-band SAW

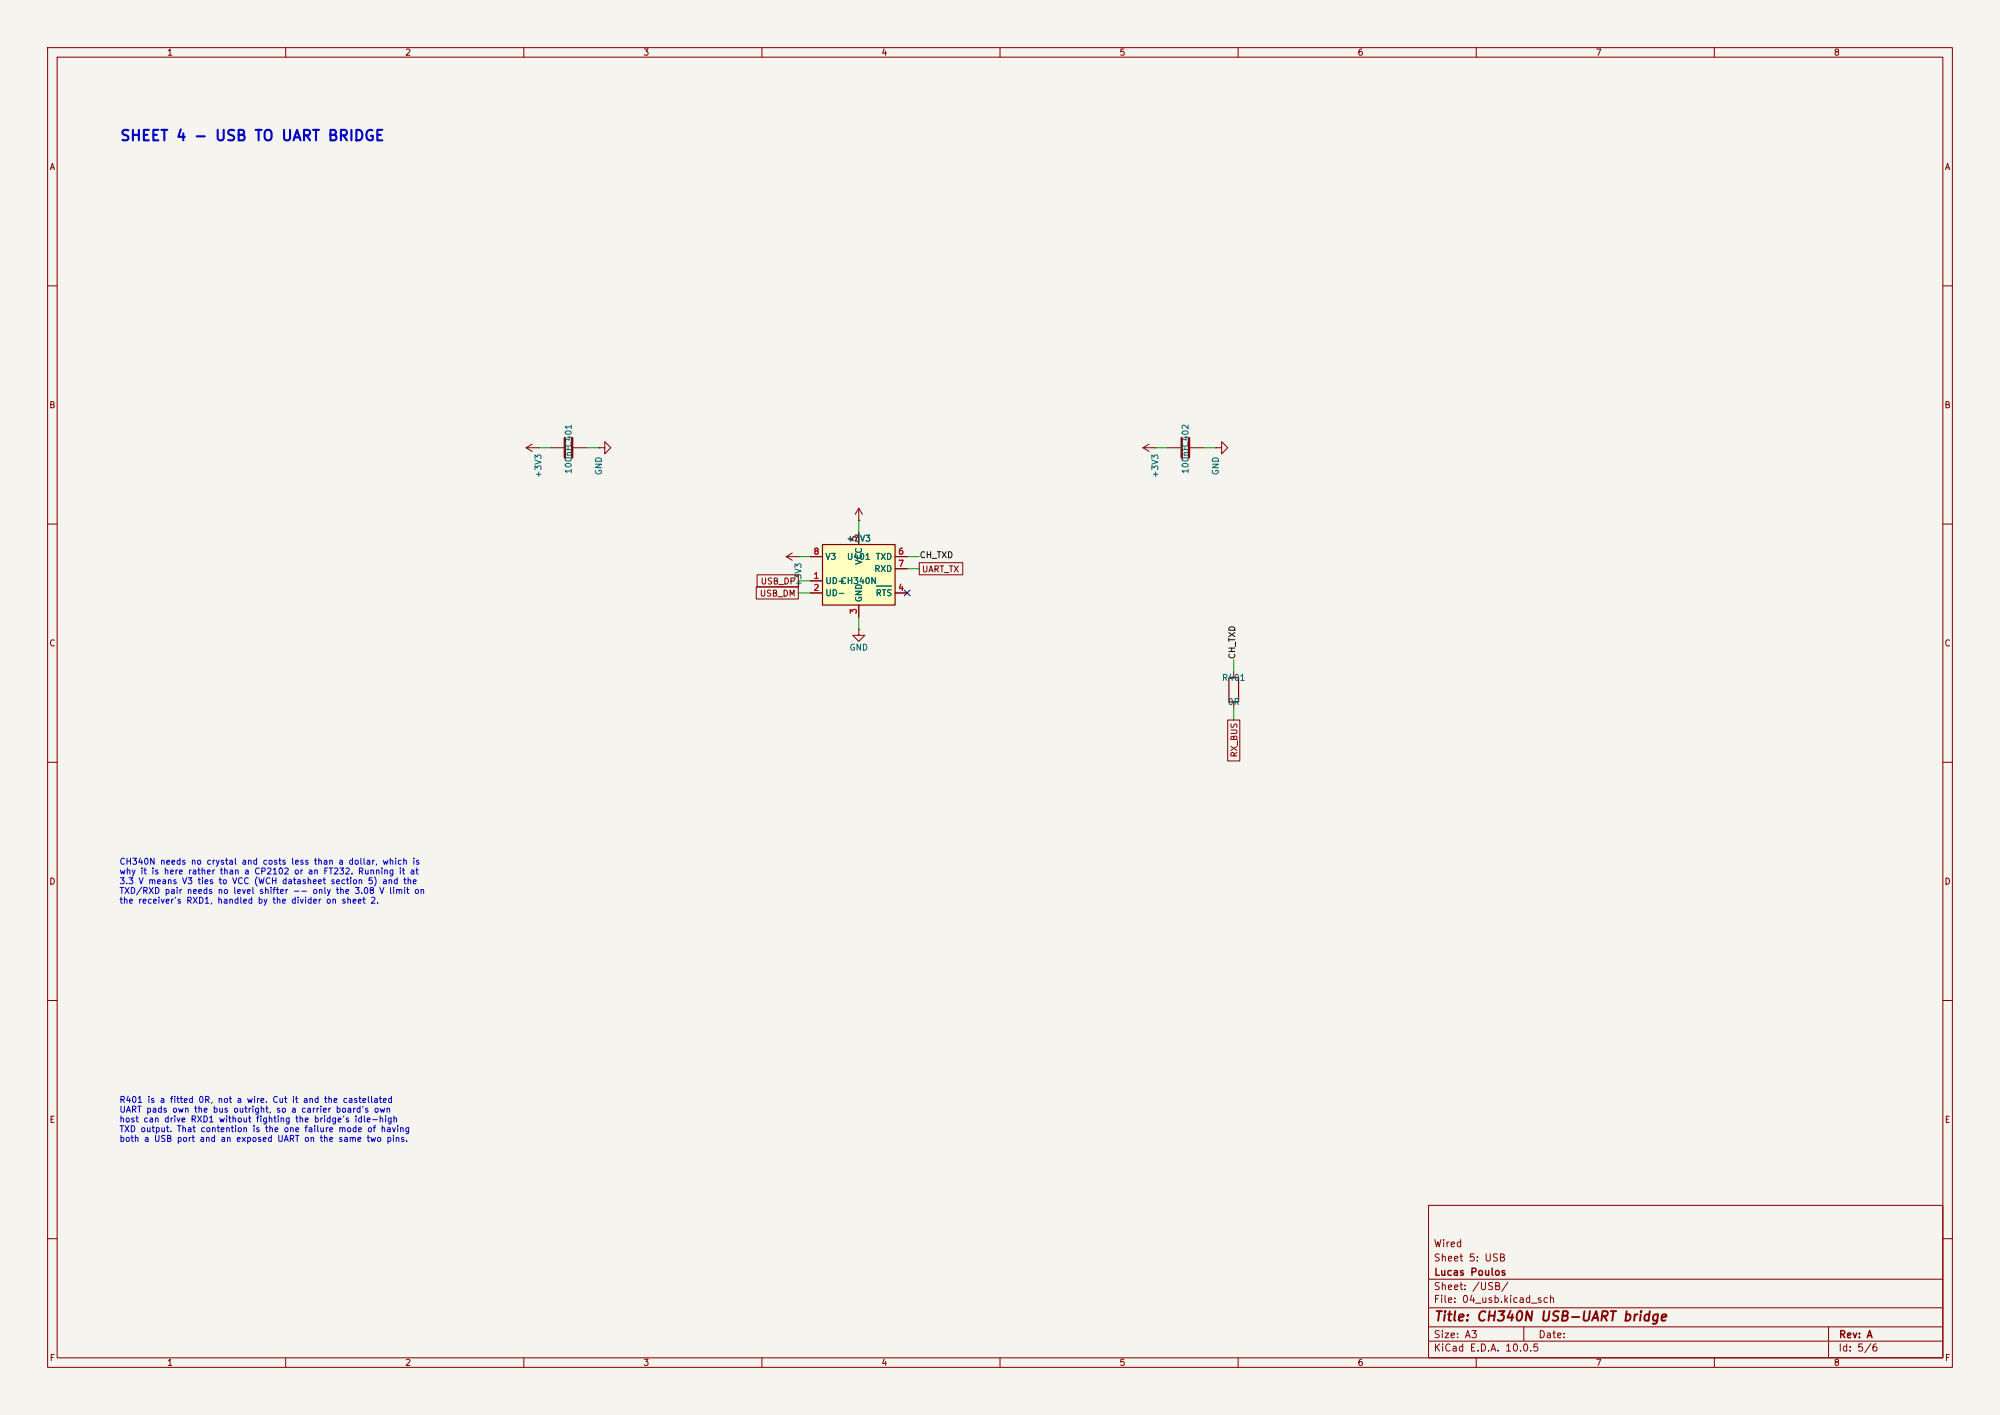
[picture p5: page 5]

CH_TXD SHEET 4 - USB TO UART BRIDGE
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

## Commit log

2026-09-28 Cheap dual-band RTK GNSS module: schematic complete and verified
    LC29H (DA) dual-band L1+L5 RTK rover with a fully discrete 50 ohm front
    end, USB-C via CH340N, and 24 castellated pads on 1.27 mm. Corrections
    arrive from the host as RTCM3 over UART1, so there is no radio on board.
    $27.10/board at qty 1, of which the receiver is 88%.
    Everything except the receiver and its SAW is discrete: the antenna bias
    tee, the ANT_ON power switch, both ORing diodes, the RX level divider and
    the 1PPS driver are single transistors and passives.
    design/ is generated from scripts/ -- deterministic uuid5 seeds, so
    regeneration is byte-identical. verify_project.py is the gate: 146 checks
    over determinism, a p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
    [01_power.kicad_sch, 02_gnss.kicad_sch, 03_rf.kicad_sch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]
2026-09-28 Ignore KiCad 10's design/.history edit-history folder
    Opening the project in the GUI makes KiCad write a .history/ folder
    beside the design. It is local editor state, not design output.
2026-09-28 Add a Makefile and a pre-commit gate so the workflow is self-enforcing
    design/ being generated is only safe if the rules are mechanical rather
    than remembered. Two guardrails:
    - `make guard` refuses to regenerate while THIS project is open in KiCad.
    A bare `pgrep kicad` was too coarse -- it fires when the GUI has some
    other project open, which is harmless. Lock files in design/ are the
    precise signal.
    - .githooks/pre-commit runs the 146-check gate on any commit touching
    scripts/ or design/, then fails if regeneration changed design/ -- so
    the tree that gets pushed always matches the scripts that get pushed.
    Install once with `make hooks`; bypass with --no-verify.
    `make` on its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
2026-09-28 Add docs/making-changes.md and point README/CLAUDE.md at the Makefile
    A generated design/ only works if it is obvious where to edit instead.
    docs/making-changes.md is a recipe book keyed to this repo: change a
    value, add a part, rewire a net, add a DNP option, move the impedance
    target, swap the receiver variant -- each with the exact file and the
    gate failure you get if you miss a step.
    It also documents what each of the 146 checks means when it fails, and
    which things nothing checks (the README pinout tables, the frozen price
    snapshot, and whether the circuit actually works).
2026-09-28 Adopt KiCad's own file format as the baseline
    Opening the project in eeschema rewrote all seven files in KiCad's
    canonical format -- generator "gen_project.py" becomes "eeschema", and
    the lib_symbols indentation is normalised. +12045/-6893 lines, and
    zero design change: every net in EXPECT_NETS still has exactly the same
    membership and every netclass still resolves.
    Also resyncs design/lib/rtk-gps-module.kicad_sym from the schematic's
    own cached copies. Opening the Symbol Editor on U201 left the cache and
    the library disagreeing, which ERC reported as lib_symbol_mismatch.
    Rebuilding the library from the cache clears it: ERC is 0 errors,
    0 warnings again.
    This is the point where hand editin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
    [01_power.kicad_sch, 02_gnss.kicad_sch, 03_rf.kicad_sch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]
2026-09-28 Convert to a normal, directly-editable KiCad project
    design/ is now the source of truth. Open it in KiCad, change it, save
    it. Nothing regenerates it and nothing in tools/ writes to it.
    The generate-then-verify workflow was getting in the way more than it
    was helping: every `make` command rebuilt design/ from Python, so a GUI
    edit could not survive, and the pre-commit hook enforced that.
    What changed:
    - scripts/ -> tools/bootstrap/, frozen, with a README saying not to run
    them and what is still worth reading in them (the LC29H pinout
    transcribed twice over from Table 6, the land-pattern derivations,
    the resolved parts catalogue).
    - tools/check.py replaces the 146-check gate with 32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
2026-11-06 Add the PCB with all 64 footprints placed
    Placement only -- this is the starting point for layout, not a routed
    board. What is in here:
    - 64 footprints positioned across roughly 38 x 36 mm, 62 SMD + 2 THT
    - a top_keepout zone over the antenna area (vias, pads and copper pour
    all disallowed) so a later ground pour cannot detune the RF front end
    - two copper layers, F.Cu and B.Cu
    What is deliberately still missing, in the order it needs doing:
    - Edge.Cuts is empty, there is no board outline yet
    - no ground pour, which the 50 ohm work in docs/impedance.md assumes
    - nothing routed: zero track segments, zero vias
    - no fiducials, which assembly will need given the 0.30 mm finest pad
    The .kic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
2026-11-06 Let KiCad renormalise four sheets, and drop two redundant +3V3 flags
    The result of opening the project in the KiCad 10 GUI and saving. Most of
    the diff is KiCad rewriting the generator's output in its own idiom:
    - refreshed lib_symbols cache blocks
    - normalised property field positions
    - explicit junction objects where the generator relied on wire geometry
    - reordered wire records
    One change is real rather than cosmetic: #PWR0052 and #PWR0054, two of the
    sixteen +3V3 power flags, are gone. +3V3 keeps the remaining fourteen.
    Verified equivalent against the previous revision before committing: all
    206 real component pins resolve to the same nets, no pin moved, none
    appeared or disappeared,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
2026-11-06 Regroup the placement by subsystem and draw the board outline
    Board is 40.64 x 38.10 mm, x 50.00..90.64, y 35.00..73.10. Both
    dimensions are whole multiples of 2.54 mm, so the castellation rows still
    land on 0.1 in perfboard as the README claims.
    Size is set by area, not preference. The 64 courtyards total 695 mm2 and
    U201 alone is 257 mm2 of that, so 1548 mm2 puts the board at 45% courtyard
    density -- workable on two layers. Anything near 30 x 25 mm would have
    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
2026-11-06 Make the board four layers, with the stackup impedance.md already assumed
    The board file declared two copper layers while docs/impedance.md derived
    the 0.38 mm RF width from JLCPCB's four-layer JLC04161H-3313, where the
    reference plane sits 0.2104 mm under the trace. On a 2-layer 1.6 mm board
    that plane is ~1.5 mm away and 50 ohm needs roughly 2.9 mm of width, so the
    RF netclass was off by about 7x against the stack it would have been built
    on.
    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
2026-11-06 Put the SAW beside pin 11 and run the RF chain into it
    The previous pass grouped parts by subsystem but left FL301 17 mm from
    U201 pin 11, which breaks the rule impedance.md states outright: the u.FL
    beside the SAW, the SAW beside pin 11. Pin 11 sits at U201's upper-left
    corner (63.70, 47.10), so the chain has to arrive from there, not from the
    top-right where the RF band used to be.
    The series path now runs down x = 57.8 and turns into the SAW:
    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
2026-11-06 Pour ground on L1, L2 and L4; leave L3 free for routing
    impedance.md layout rule 1 asks for solid ground under the entire RF path,
    and rule 2 for coplanar pour either side of the CPWG run. Neither existed
    -- the board had no board-level copper zone at all. (The one zone already
    in the file is a keepout nested inside the J301 footprint, so it travels
    with the connector rather than covering the board.)
    Three GND zones, outline inset 0.40 mm from the edge, which clears
    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
2026-11-06 Re-place for connectivity: ratsnest down 42%, board now square
    Size was freed as a constraint, so placement was re-solved against the
    ratsnest instead of against area. Objective is total minimum-spanning-tree
    length over every net except GND, which is poured and does not contribute
    a visible rat line.
    before 993.6 mm
    after 574.8 mm 42% shorter
    Simulated annealing, 5 restarts x 150k iterations, moves rejected on
    courtyard overlap or edge-inset violation so every candidate stays
    physically legal. Converged to the same optimum from restart 1 onward.
    Not everything moved. The RF chain is frozen as a rigid group -- U201,
    J301, C301, R301, FL301 and the six shunts -- because that p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
2026-11-06 Fix three defects KiCad's own DRC found that the python analyzer missed
    kicad-cli 10.0.5 is installed, so the board can finally be checked by
    KiCad itself rather than only by the analyzer in skills/kicad. It parses
    clean, but reported 435 violations where the analyzer had reported six
    findings. Three were mine.
    1. Rotated footprints had unrotated pads.
    KiCad writes an explicit angle on every pad of a rotated footprint --
    confirmed against dshot-esc-100a and wristband-alarm, which both do.
    Rotating via the footprint's own (at x y rot) alone turns pad
    POSITIONS but leaves pad SHAPES at angle 0. U401's 1.95 x 0.6 mm SOIC
    pads ended up lying across a 1.27 mm pitch and shorting.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
2026-11-06 Fix two land patterns that would have made the board unbuildable
    Both predate the layout work. KiCad's DRC found them; the python
    analyzer had reported neither.
    SAW B39162B8389P810 -- pad 1 was 0.2 mm out of position.
    Datasheet Figure 2 (p.5, "Land pattern THRU VIEW") dimensions the
    pattern as two 0.5 mm steps: pad 1, then the pad 2/5 column, then the
    pad 3/4 column. With the columns at x = -0.25 and +0.25, pad 1 belongs
    at -0.75. It was at -0.55.
    Pad 1 is the RF input. At -0.55 its 0.3 mm pad ended edge-to-edge with
    the grounded pads 2 and 5 at exactly 0.000 mm -- DRC measured 0.0125 mm
    against the rounded corners. JLCPCB's minimum spacing is 0.127 mm, so
    solder would hav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
2026-11-06 Add docs/plan.md -- the route from here to a working board
    Six phases, ordered by dependency rather than preference, each with the
    gate that must be true before the next begins.
    Phase 0 is four decisions only the owner can make: DA vs AA receiver,
    USB-C mounting style, assembly route now that the receiver is off LCSC,
    and surface finish. The receiver choice notably does NOT gate layout --
    AA and DA are pin-identical, verified against Figure 4 and Table 6 of the
    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
2026-11-06 Move the USB-C to the board edge so a cable can actually reach it
    Plan 0.2, and it turned out to be a defect rather than a preference.
    USB_C_Receptacle_HRO_TYPE-C-31-M-12 carries no Edge.Cuts geometry, so it
    is not mid-mount -- it is a horizontal top-mount receptacle. Its pads
    occupy the back 6.6 mm of the footprint and the remaining 2.3 mm of
    courtyard is the plug opening.
    J101 sat at y=67.300, putting that opening at y=71.45 with the board edge
    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
2026-11-06 Make the impedance check read the board, so it can actually fail
    Plan 3.4. calc_impedance.py hardcoded h = 0.2104 and took no arguments, so
    "RF impedance ok" was the model agreeing with itself. It could not detect
    the board drifting away from the stackup the 0.38 mm width is solved for --
    and it didn't: the board sat at two copper layers, where the reference
    plane is ~1.5 mm down rather than 0.2104 mm, for several commits with the
    check reporting ok the whole time. KiCad's DRC found it; this check never
    could have.
    calc_impedance.py gains read_board_stackup(), which parses the board's
    (layers) and (stackup) blocks for the copper layer order, and the
    thickness and epsilon_r of the dielectric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
2026-11-06 Clear three ERC warnings; document why the fourth must stay
    Plan 1.1. ERC 4 warnings -> 1.
    Fixed:
    1. A dangling 2.54 mm wire stub in 02_gnss running from the junction at
    (236.22, 121.92) out to (233.68, 121.92), where nothing exists. Deleted,
    along with the junction, which was then joining two collinear wire ends
    and so meant nothing.
    2. The SCL_INT label and its wire endpoint sat at (257.7696, 131.2823),
    off the 1.27 mm grid, joined to the real junction at (257.81, 132.08) by
    a 0.8 mm diagonal sliver. Snapped both to (257.81, 130.81), which makes
    it a clean vertical 1.27 mm label stub.
    3. An orphan no-connect flag at (312.42, 77.47) in 01_power with no pin
    anywhere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
2026-11-06 Exempt the castellated pads from edge clearance, so DRC can be a gate
    Plan 2.1. 24 copper_edge_clearance errors -> 0, with the board-wide rule
    left fully live everywhere else.
    A castellated pad is a plated half-hole: the outline router runs through
    the middle of the drill, so the pad must reach the edge. The board-wide
    0.5 mm copper-to-edge rule is right for every other object and wrong by
    construction for these 24 pads. Left in place it produces 24 permanent
    errors that bury whatever real error appears next during routing, which
    makes DRC useless exactly when routing starts.
    Syntax taken from the working .kicad_dru files in stm32mp157-devkit and
    red-light-panel rather than written from me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
2026-11-06 Add three fiducials, clearing FD-001
    Plan 2.3. Fiducial:Fiducial_1mm_Mask2mm, three of them on F.Cu, which is
    the side carrying all 62 SMD parts. The finest pad on the board is 0.30 mm,
    so the placement machine needs optical registration.
    FID1 (52.550, 64.650)
    FID2 (88.250, 73.250)
    FID3 (52.350, 37.350)
    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
2026-11-06 Make In2.Cu a +3V3 plane, clearing the stackup EMC error
    Phase 3 EMC found a real flaw I introduced two commits into layout.
    Pouring ground on L1/L2/L4 and leaving In2.Cu "free for routing" left
    In2.Cu and B.Cu as adjacent signal layers with no reference plane between
    them -- SU-001, error severity. B.Cu had no reference at all, which means
    uncontrolled return paths and high interlayer crosstalk on everything
    routed there.
    Now the classic four-layer arrangement:
    F.Cu signal referenced to In1.Cu
    In1.Cu GND plane the RF reference the 50 ohm width depends on
    In2.Cu +3V3 plane reference for B.Cu, and the power distribution
    B.Cu signal referenced to In2.Cu
    +3V3 ra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
2026-11-06 Round the board corners at R=1.5 mm
    Four Edge.Cuts straight segments replaced by four shortened edges plus
    four arcs, written as a single closed clockwise loop.
    R=1.5 mm is the largest radius that clips nothing. Swept 1.0 through
    3.0 mm against every courtyard: at 2.0 mm the bottom-left arc starts
    cutting into J101, which now sits at that corner since the USB-C was moved
    to the edge. The castellation rows span y 46.1..62.0, nowhere near a
    corner, so they were never the constraint.
    The GND and +3V3 zone outlines are left rectangular -- KiCad clips zone
    fill to the board edge minus clearance, so they follow the arcs
    automatically.
    DRC reports only the 152 unconnected items, which also confi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
2026-11-06 Re-solve capacitor placement against decoupling distance
    The connectivity pass minimised total MST length, which pulls a cap toward
    its whole net rather than toward the specific power pin it decouples.
    Measuring the thing that matters -- IC power pad to nearest cap pad on the
    same net -- showed U201's main supply decoupling sitting 7.67 mm away.
    Re-annealed the 16 movable capacitors against a combined objective:
    decoupling distance weighted 6x, plus total ratsnest. Everything else
    frozen, including the RF chain, both connectors, the three ICs and the
    fiducials. Corner-arc clearance folded into the legality test so no cap
    can land in a rounded corner.
    U201.23 +3V3 7.67 -> 4.21 mm
    U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
2026-11-06 Route the 50 ohm antenna path and stitch its coplanar ground
    First copper on this board. 8 segments, 9.9 mm of track, 12 stitching vias.
    DRC reports zero clearance or shorting errors.
    Routing exposed a placement fault first. The series parts were oriented
    backwards against signal flow: C301's output pad sat at y=41.52 while its
    input pad was at y=42.48, with J301 feeding in from y=39.53 above. A
    straight track from the connector to C301's input would have run directly
    over C301's output pad and shorted ANT_RF to RF_A. R301 had the same
    problem. Both rotated 180 degrees, which makes the chain monotonic top to
    bottom:
    J301.1 39.525 ANT_RF
    C301.1 41.520 ANT_RF
    C301.2 42.480 RF_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
2026-11-06 Correct the RTK rate, and record correction sourcing for US use
    The README's spec table claimed "Update rate | up to 10 Hz" on a board
    whose entire purpose is RTK. Quectel's LC29H (BA,CA,DA,EA) DR&RTK
    Application Note says otherwise:
    LC29H (DA) only supports RTK (update rate: 1 Hz).
    LC29H (EA) only supports RTK (update rate: 1-10 Hz, 10 Hz by default).
    10 Hz is the ordinary position rate. With RTK engaged the DA produces one
    fix per second. The table now carries both numbers separately and says
    which is which.
    This also corrects the DA-vs-AA comparison in docs/plan.md, which listed
    the AA's 1 Hz raw-observation cap as a cost of moving the RTK engine to
    the host. It is not a cost: the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
